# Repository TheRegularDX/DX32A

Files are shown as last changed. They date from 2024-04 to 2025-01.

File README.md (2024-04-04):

# DX32A DELUXE
This is the base DX32 model. The DX32A DELUXE is a custom development board based on the Espressif ESP32S3 N16R8 WiFi and Bluetooth module. designed to be simple and breadboard compatible

## Features
- WiFi and BLE
- x25 GPIO pins
- x1 WS2812B addresable RGB led
- x1 MicroSD card reader

## PlatformIO support
Ive added to this repo a slightly modified version of the official S3 DevKitC .json file to this repo, drag and drop it into `.platformio/platforms/espressif32/boards` to add the DX32 to the PlatformIO boards selector, this can also be used with any other board based on the ESP32S3 N16R8

## Faq
>why it name delucks?

just because i think deluxe is a cool word in general.

## Name change
As of 31/3/24 this board has been renamed to just "DELUXE" instead of "DELUXE Mini", the latter will be reused for a future board

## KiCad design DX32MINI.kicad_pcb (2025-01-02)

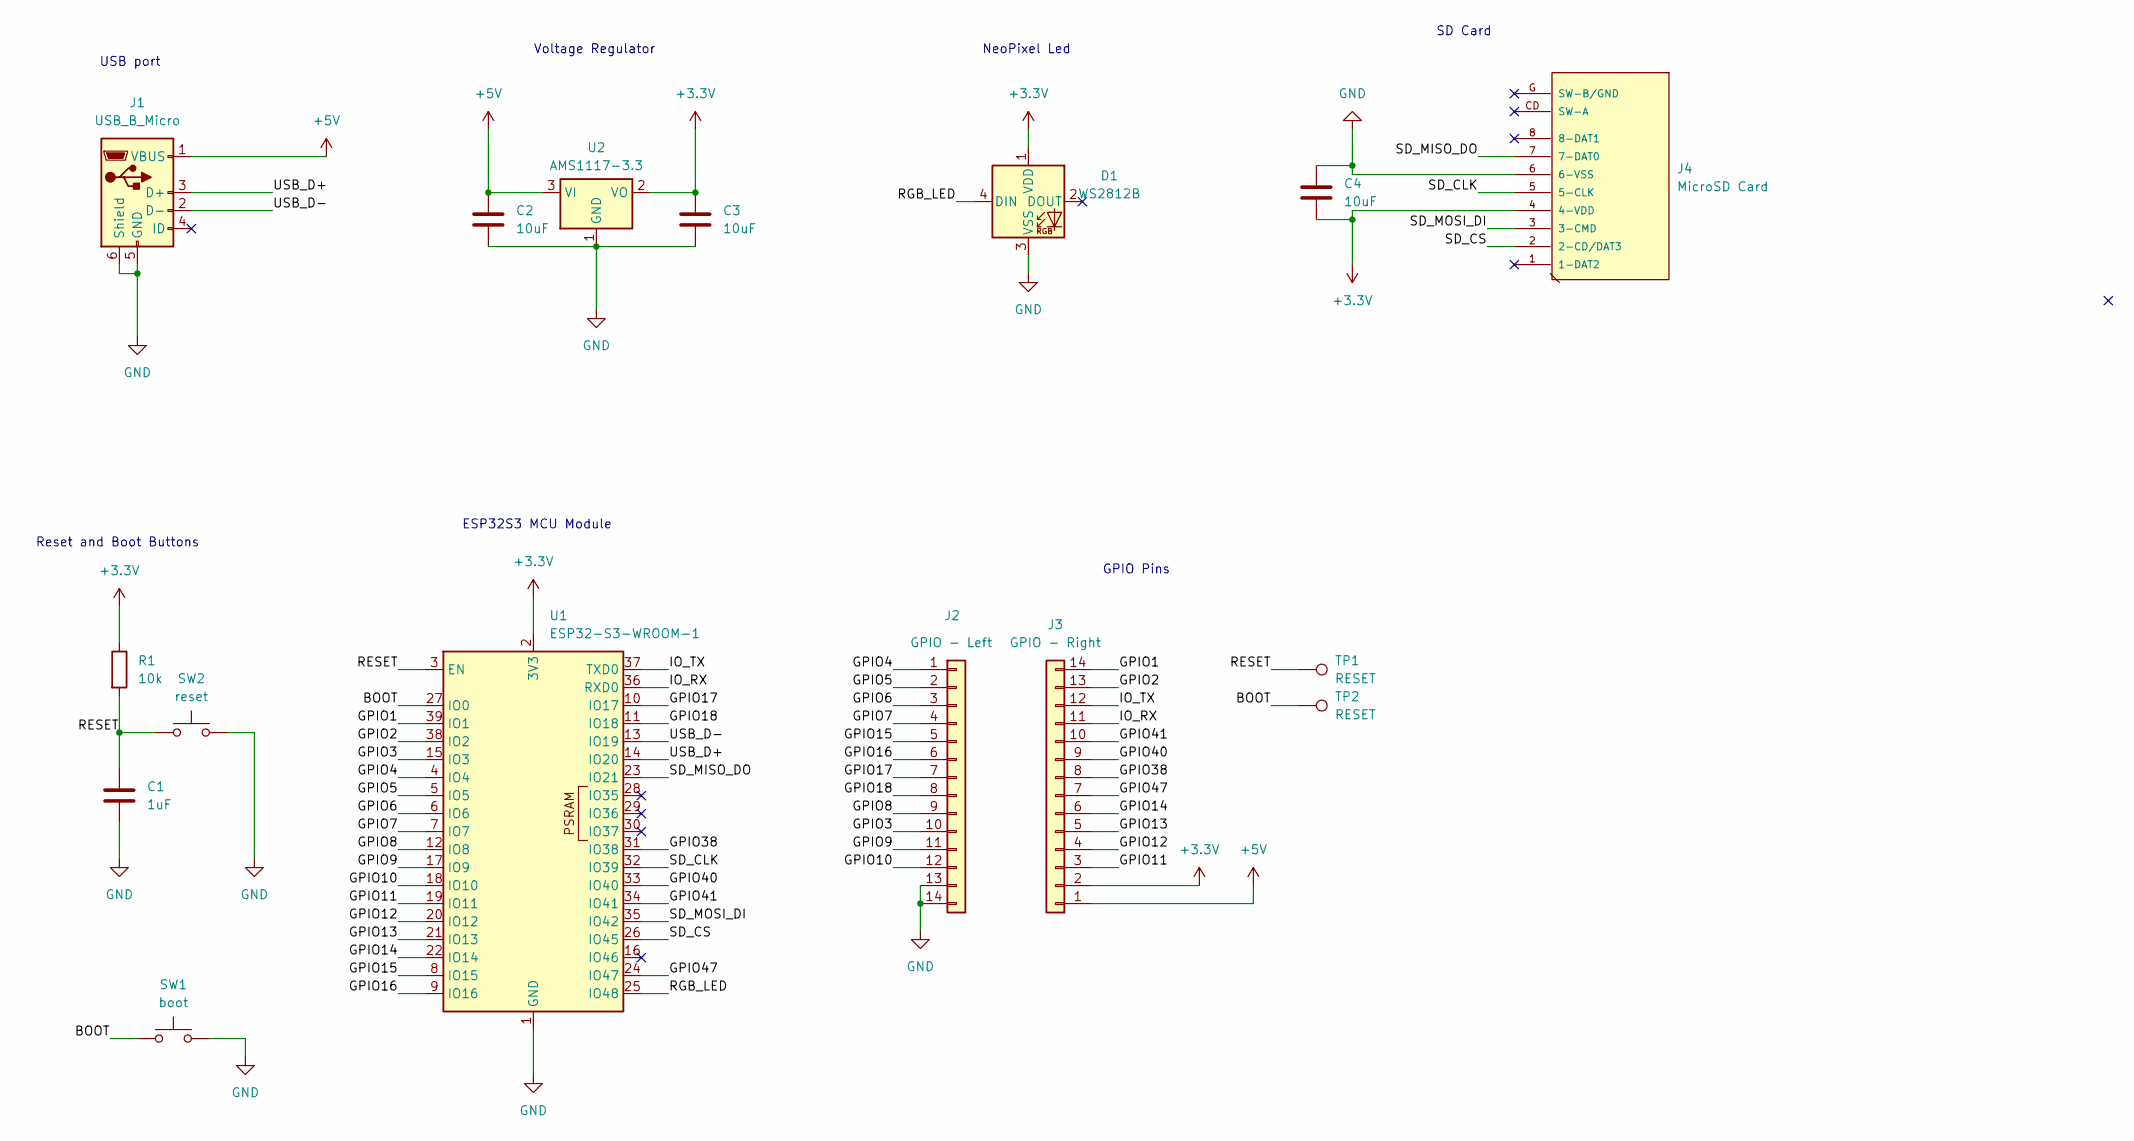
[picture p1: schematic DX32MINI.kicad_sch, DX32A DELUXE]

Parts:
C1: 1uF; C_0805_2012Metric_Pad1.18x1.45mm_HandSolder
C2, C3, C4: 10uF; C_0805_2012Metric_Pad1.18x1.45mm_HandSolder
D1: WS2812B; LED_WS2812B_PLCC4_5.0x5.0mm_P3.2mm
J1: USB_B_Micro; USB_Micro-B_Molex-105017-0001
J2: GPIO - Left; PinHeader_1x14_P2.54mm_Vertical
J3: GPIO - Right; PinHeader_1x14_P2.54mm_Vertical
J4: MicroSD Card; 112J-TDAR-R01
R1: 10k; R_0805_2012Metric_Pad1.20x1.40mm_HandSolder
SW1: boot; SW_Push_SPST_NO_Alps_SKRK
SW2: reset; SW_Push_SPST_NO_Alps_SKRK
TP1, TP2: RESET; TestPoint_Pad_1.5x1.5mm
U1: ESP32-S3-WROOM-1
U2: AMS1117-3.3; SOT-223-3_TabPin2

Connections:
+3.3V: C3.1, C4.2, D1.1 (VDD), J3.2, J4.4 (4-VDD), R1.1, U1.2 (3V3), U2.2 (VO)
+5V: C2.1, J1.1 (VBUS), J3.1, U2.3 (VI)
/BOOT: SW1.1, TP2.1, U1.27 (IO0)
/GPIO1: J3.14, U1.39 (IO1)
/GPIO2: J3.13, U1.38 (IO2)
/GPIO3: J2.10, U1.15 (IO3)
/GPIO4: J2.1, U1.4 (IO4)
/GPIO5: J2.2, U1.5 (IO5)
/GPIO6: J2.3, U1.6 (IO6)
/GPIO7: J2.4, U1.7 (IO7)
/GPIO8: J2.9, U1.12 (IO8)
/GPIO9: J2.11, U1.17 (IO9)
/GPIO10: J2.12, U1.18 (IO10)
/GPIO11: J3.3, U1.19 (IO11)
/GPIO12: J3.4, U1.20 (IO12)
/GPIO13: J3.5, U1.21 (IO13)
/GPIO14: J3.6, U1.22 (IO14)
/GPIO15: J2.5, U1.8 (IO15)
/GPIO16: J2.6, U1.9 (IO16)
/GPIO17: J2.7, U1.10 (IO17)
/GPIO18: J2.8, U1.11 (IO18)
/GPIO38: J3.8, U1.31 (IO38)
/GPIO40: J3.9, U1.33 (IO40)
/GPIO41: J3.10, U1.34 (IO41)
/GPIO47: J3.7, U1.24 (IO47)
/IO_RX: J3.11, U1.36 (RXD0)
/IO_TX: J3.12, U1.37 (TXD0)
/RESET: C1.1, R1.2, SW2.1, TP1.1, U1.3 (EN)
/RGB_LED: D1.4 (DIN), U1.25 (IO48)
/SD_CLK: J4.5 (5-CLK), U1.32 (IO39)
/SD_CS: J4.2 (2-CD/DAT3), U1.26 (IO45)
/SD_MISO_DO: J4.7 (7-DAT0), U1.23 (IO21)
/SD_MOSI_DI: J4.3 (3-CMD), U1.35 (IO42)
/USB_D+: J1.3 (D+), U1.14 (IO20)
/USB_D-: J1.2 (D-), U1.13 (IO19)
GND: C1.2, C2.2, C3.2, C4.1, D1.3 (VSS), J1.5 (GND), J1.6 (Shield), J2.13, J2.14, J4.6 (6-VSS), SW1.2, SW2.2, U1.1 (GND), U1.40 (GND), U1.41 (GND), U2.1 (GND)

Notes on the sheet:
ESP32S3 MCU Module
Voltage Regulator
SD Card
GPIO Pins
USB port
NeoPixel Led
Reset and Boot Buttons

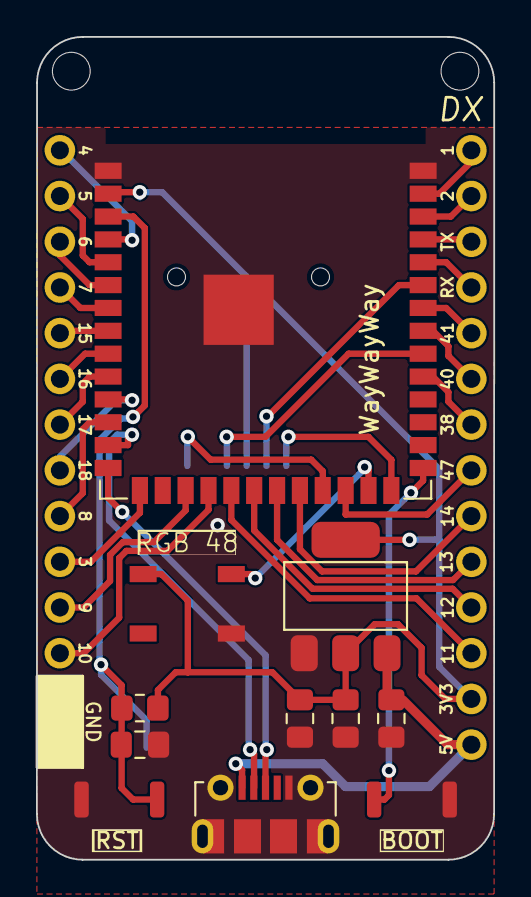
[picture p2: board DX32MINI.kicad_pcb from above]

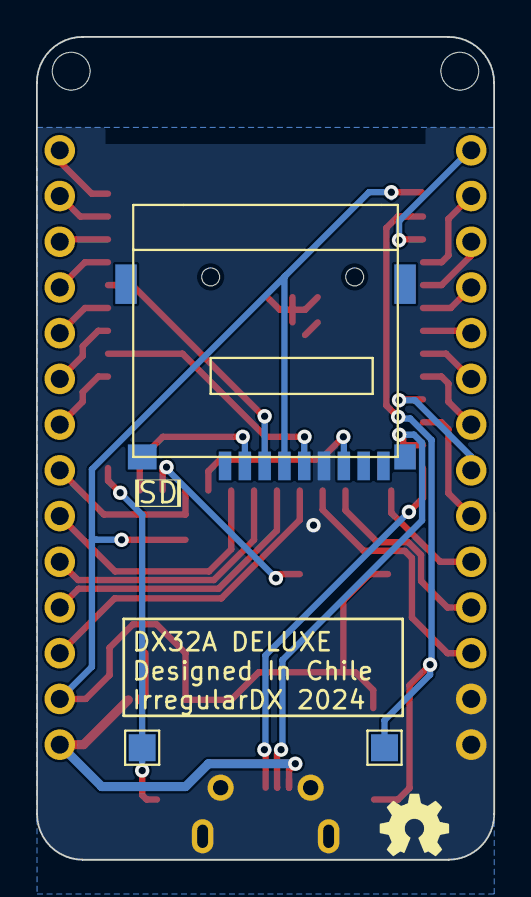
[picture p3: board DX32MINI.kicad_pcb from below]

Board: 2 copper layers, 25.4 x 45.7 mm, 18 parts (3 on the bottom side), 36 nets.

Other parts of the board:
anotherhole: MountingHole_2.1mm
hole: MountingHole_2.1mm
